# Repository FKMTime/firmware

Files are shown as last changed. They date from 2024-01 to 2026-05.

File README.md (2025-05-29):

# FKM Timer

## Main Pinout

| # | IO# | ADC/STRAP/USB | USAGE | Notes |
|-----|---|---|---|---|
| 0 | IO4 | ADC | SPI SCK | |
| 1 | IO5 | ADC | SPI MISO | |
| 2 | IO6 | | SPI MOSI | |
| 3 | IO7 | | | |
| 4 | IO8 | STRAP | | |
| 5 | IO9 | STRAP / IPU | | INTERNAL PULLUP (10kOhm) |
| 6 | IO10  | | SHIFTER DATA | |
| 7 | RXD/IO20| | JACK INPUT | |
| 8 | TXD/IO21| | SHIFTER CLK | |
| 9 | IO18  | USB | USB D- | |
| 10  | IO19  | USB | USB D+ | |
| 11  | IO3 | ADC | BUTTON INPUT | |
| 12  | IO2 | ADC / STRAP | BATTERY INPUT  | |
| 13  | IO1 | ADC | SHIFTER LATCH  | |
| 14  | IO0 | ADC | | |

**Notes:**
* **STRAP:** Strapping pin
* **IPU:** Internal Pull-up (10kOhm).
* **USB:** Pins used for USB communication.

## Shifters Configuration

| SHIFTER # | USAGE | BIT1 | BIT2 | BIT3 | BIT4 | BIT5 | BIT6 | BIT7 | BIT8 |
|---|---|---|---|---|---|---|---|---|---|
| 0 | BUTTONS MATRIX | BTN1 | BTN2 | BTN3 | BTN4 | | | | |
| 1 | LCD 16x2 | SPI_CS  | BL | RS | E | D7 | D6 | D5 | D4 |
| 2 | DISPLAY DIGIT1 | TODO | TODO | TODO | TODO | TODO | TODO | TODO | TODO |
| 3 | DISPLAY DIGIT2 | TODO | TODO | TODO | TODO | TODO | TODO | TODO | TODO |
| 4 | DISPLAY DIGIT3 | TODO | TODO | TODO | TODO | TODO | TODO | TODO | TODO |
| 5 | DISPLAY DIGIT4 | TODO | TODO | TODO | TODO | TODO | TODO | TODO | TODO |
| 6 | DISPLAY DIGIT5 | TODO | TODO | TODO | TODO | TODO | TODO | TODO | TODO |
| 7 | DISPLAY DIGIT6 | TODO | TODO | TODO | TODO | TODO | TODO | TODO | TODO |

## PCB
Pcb files are available as easyeda pro project.
File `FKM3.epro`

## 3D design 
You can view it and/or export it on onshape: 
 - [v1](https://cad.onshape.com/documents/a197fb44982d02cf4b905a34/w/d4d582c400841c8d2afd5356/e/063a9ed468737fb6f67b27f0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)
 - [v2](https://cad.onshape.com/documents/b9e6ecc4d8625f5993c3f9f8/w/500dd0485ca5c8c194e3d3fd/e/a40639e650796ab94408e0d7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)

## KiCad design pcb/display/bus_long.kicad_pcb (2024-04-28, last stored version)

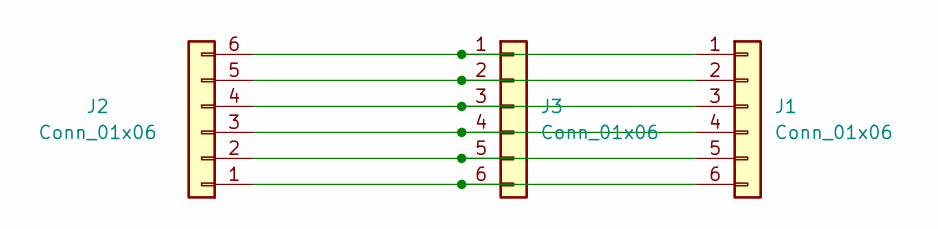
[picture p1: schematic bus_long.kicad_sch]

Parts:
J1, J2, J3: Conn_01x06; PinHeader_1x06_P2.54mm_Vertical

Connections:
unnamed: J1.1, J2.6, J3.1
unnamed: J1.2, J2.5, J3.2
unnamed: J1.3, J2.4, J3.3
unnamed: J1.4, J2.3, J3.4
unnamed: J1.5, J2.2, J3.5
unnamed: J1.6, J2.1, J3.6

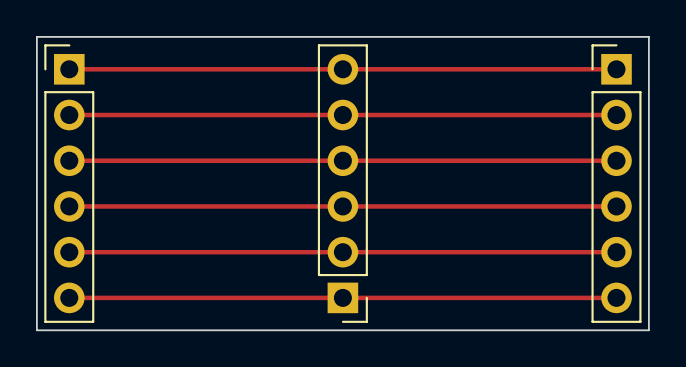
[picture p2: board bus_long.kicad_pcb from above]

Board: 2 copper layers, 34.0 x 16.3 mm, 3 parts (0 on the bottom side), 6 nets.

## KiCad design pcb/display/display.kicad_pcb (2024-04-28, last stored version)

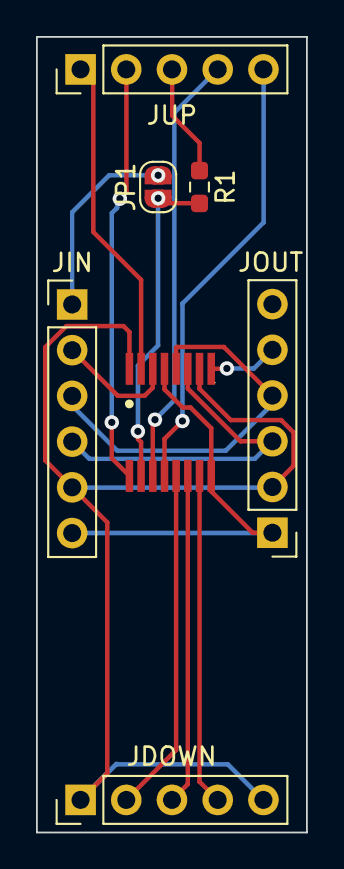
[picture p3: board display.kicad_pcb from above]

Board: 2 copper layers, 15.0 x 44.2 mm, 7 parts (0 on the bottom side), 16 nets.

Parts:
JDOWN: DOWN; PinHeader_1x05_P2.54mm_Vertical
JIN: INPUT; PinHeader_1x06_P2.54mm_Vertical
JOUT: OUTPUT; PinHeader_1x06_P2.54mm_Vertical
JP1: SolderJumper_2_Open; SolderJumper-2_P1.3mm_Open_RoundedPad1.0x1.5mm
JUP: UP; PinHeader_1x05_P2.54mm_Vertical
R1: R220; R_0603_1608Metric_Pad0.98x0.95mm_HandSolder
U1: 74HC595; TSSOP16

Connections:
8_O: JIN.1, JP1.2 (B)
+5V: JDOWN.1, JDOWN.5, JIN.5, JOUT.2, U1.10 (~SRCLR), U1.16 (VCC)
DS: JIN.2, U1.14 (SER)
DS_O: JOUT.5, U1.9 (QH')
GND: JIN.6, JOUT.1, U1.8 (GND), U1.13 (~OE)
unnamed: JUP.3, R1.1
QA: JUP.1, U1.15 (QA)
QB: JUP.2, U1.1 (QB)
QC: JP1.1 (A), R1.2, U1.2 (QC)
QD: JUP.4, U1.3 (QD)
QE: JUP.5, U1.4 (QE)
QF: JDOWN.2, U1.5 (QF)
QG: JDOWN.3, U1.6 (QG)
QH: JDOWN.4, U1.7 (QH)
SHCP: JIN.4, JOUT.3, U1.11 (SRCLK)
STCP: JIN.3, JOUT.4, U1.12 (RCLK)

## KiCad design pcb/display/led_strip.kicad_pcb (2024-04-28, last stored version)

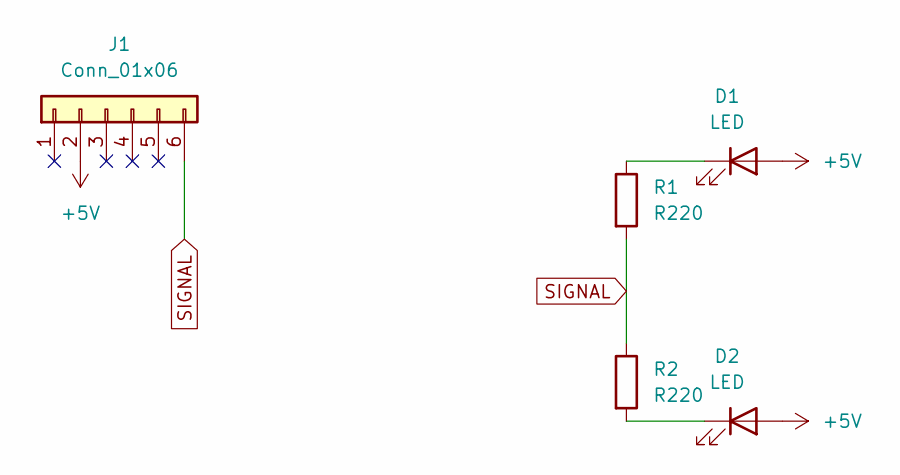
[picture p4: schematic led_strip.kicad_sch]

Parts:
D1, D2: LED; LED_D3.0mm
J1: Conn_01x06; PinHeader_1x06_P2.54mm_Vertical
R1, R2: R220; R_0603_1608Metric_Pad0.98x0.95mm_HandSolder

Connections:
+5V: D1.2 (A), D2.2 (A), J1.2
unnamed: D1.1 (K), R1.1
unnamed: D2.1 (K), R2.2
SIGNAL: J1.6, R1.2, R2.1

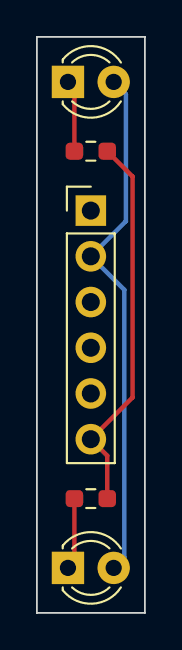
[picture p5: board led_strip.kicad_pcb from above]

Board: 2 copper layers, 6.0 x 32.0 mm, 5 parts (0 on the bottom side), 4 nets.

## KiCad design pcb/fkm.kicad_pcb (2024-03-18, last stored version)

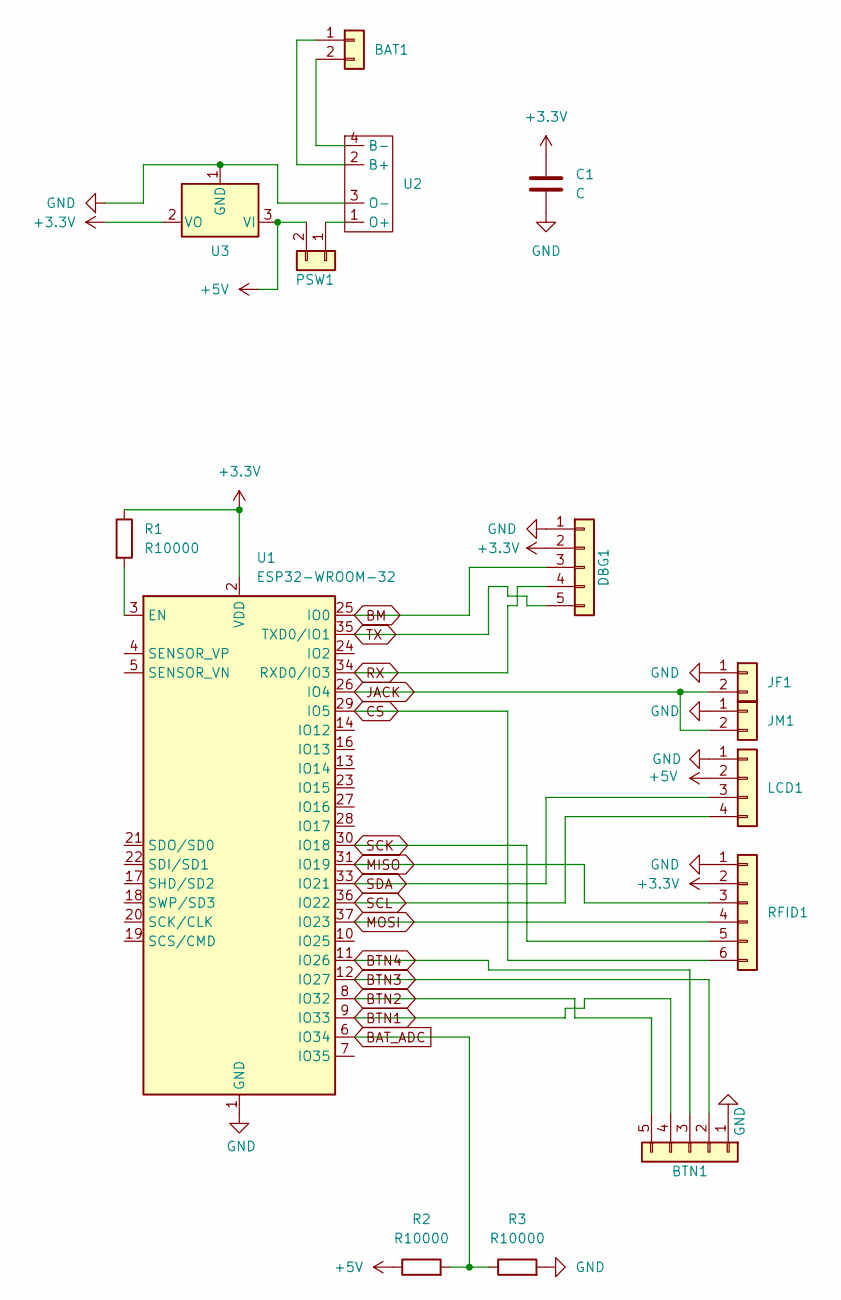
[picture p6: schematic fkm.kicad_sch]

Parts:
BAT1: BAT1; PinHeader_1x02_P2.54mm_Vertical
BTN1: Conn_01x05; PinHeader_1x05_P2.54mm_Vertical
C1: C; C_0805_2012Metric_Pad1.18x1.45mm_HandSolder
DBG1: Conn_01x05; PinHeader_1x05_P2.00mm_Vertical
JF1: JACK_FEMALE; PinHeader_1x02_P2.54mm_Vertical
JM1: JACK_MALE; PinHeader_1x02_P2.54mm_Vertical
LCD1: LCD; PinHeader_1x04_P2.54mm_Vertical
PSW1: POWER_SW; PinHeader_1x02_P2.54mm_Vertical
R1, R2, R3: R10000; R_0805_2012Metric_Pad1.20x1.40mm_HandSolder
RFID1: RFID; PinHeader_1x06_P2.54mm_Vertical
U1: ESP32-WROOM-32
U2: 18650; 18650usbc
U3: AMS1117-3.3; SOT-223-3_TabPin2

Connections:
+3.3V: C1.2, DBG1.2, R1.1, RFID1.2, U1.2 (VDD), U3.2 (VO)
+5V: LCD1.2, PSW1.2, R2.1, U3.3 (VI)
BAT_ADC: R2.2, R3.1, U1.6 (IO34)
BM: DBG1.3, U1.25 (IO0)
BTN1: BTN1.4, U1.9 (IO33)
BTN2: BTN1.5, U1.8 (IO32)
BTN3: BTN1.2, U1.12 (IO27)
CS: RFID1.6, U1.29 (IO5)
GND: BTN1.1, C1.1, DBG1.1, JF1.1, JM1.1, LCD1.1, R3.2, RFID1.1, U1.1 (GND), U1.15 (GND), U1.38 (GND), U1.39 (GND), U2.3 (O-), U3.1 (GND)
JACK: JF1.2, JM1.2, U1.26 (IO4)
MISO: RFID1.3, U1.31 (IO19)
MOSI: RFID1.4, U1.37 (IO23)
unnamed: BAT1.1, U2.2 (B+)
unnamed: BAT1.2, U2.4 (B-)
unnamed: BTN1.3, U1.11 (IO26)
unnamed: PSW1.1, U2.1 (O+)
unnamed: R1.2, U1.3 (EN)
RX: DBG1.4, U1.34 (RXD0/IO3)
SCK: RFID1.5, U1.30 (IO18)
SCL: LCD1.4, U1.36 (IO22)
SDA: LCD1.3, U1.33 (IO21)
TX: DBG1.5, U1.35 (TXD0/IO1)

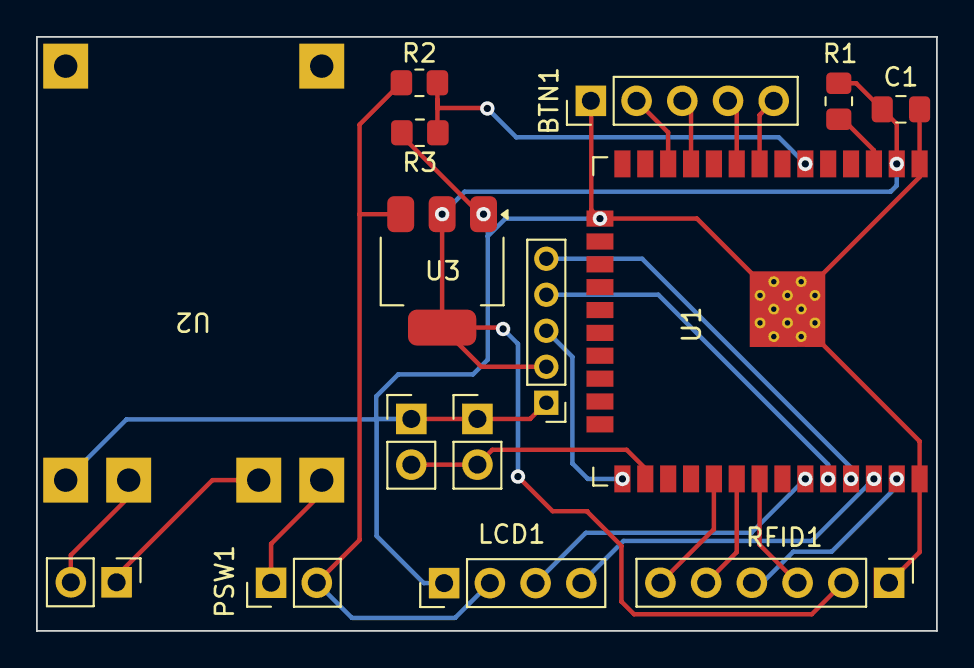
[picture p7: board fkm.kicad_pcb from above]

Board: 2 copper layers, 50.0 x 33.0 mm, 15 parts (0 on the bottom side), 22 nets.

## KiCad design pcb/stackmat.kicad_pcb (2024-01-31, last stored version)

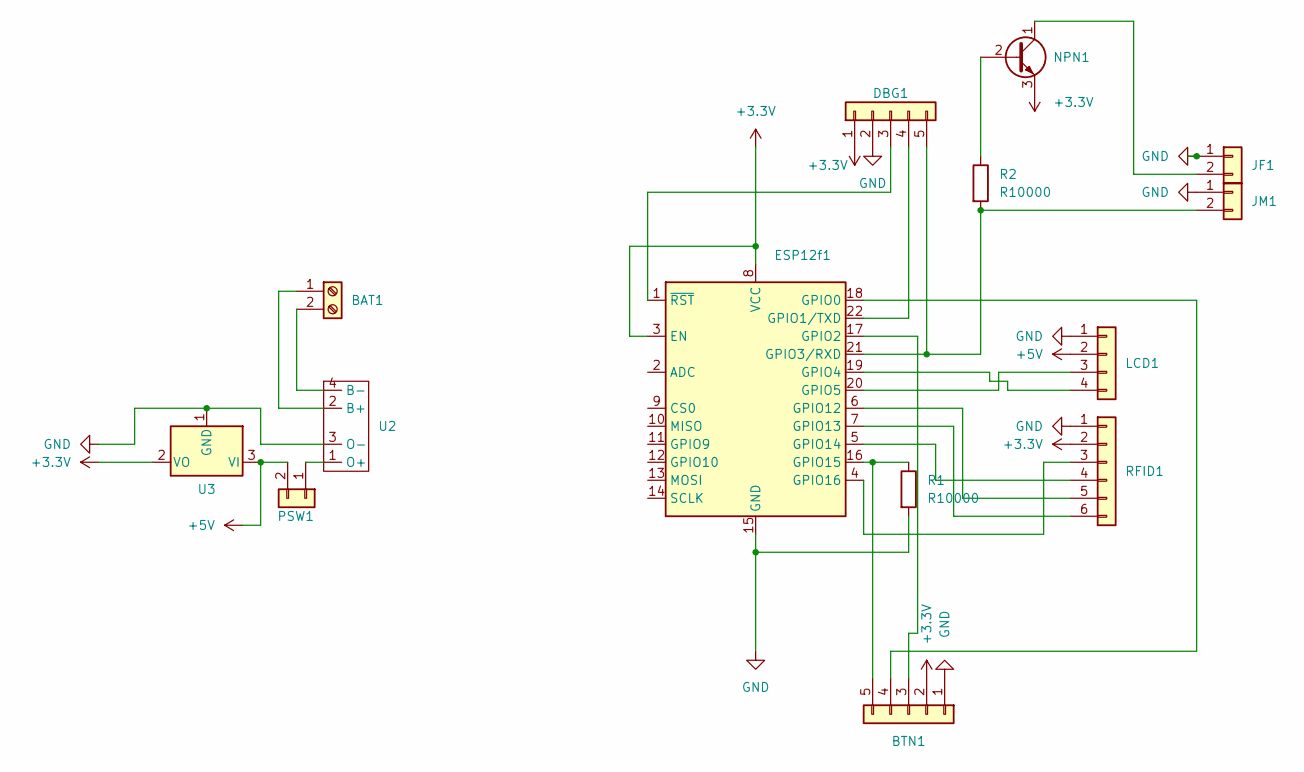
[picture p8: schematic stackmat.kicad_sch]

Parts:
BAT1: Screw_Terminal_01x02; TerminalBlock_4Ucon_1x02_P3.50mm_Horizontal
BTN1: Conn_01x05; PinHeader_1x05_P2.54mm_Vertical
DBG1: Conn_01x05; PinHeader_1x05_P2.54mm_Vertical
ESP12f1: ESP-12F/E; ESP-12E
JF1: JACK_FEMALE; PinHeader_1x02_P2.54mm_Vertical
JM1: JACK_MALE; PinHeader_1x02_P2.54mm_Vertical
LCD1: LCD; PinHeader_1x04_P2.54mm_Vertical
NPN1: BC337; TO-92_Inline
PSW1: POWER_SW; PinHeader_1x02_P2.54mm_Vertical
R1, R2: R10000; R_Axial_DIN0204_L3.6mm_D1.6mm_P7.62mm_Horizontal
RFID1: RFID; PinHeader_1x06_P2.54mm_Vertical
U2: 18650; 18650usbc
U3: AMS1117-3.3; SOT-223-3_TabPin2

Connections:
+3.3V: BTN1.2, DBG1.1, ESP12f1.3 (EN), ESP12f1.8 (VCC), NPN1.3 (E), RFID1.2, U3.2 (VO)
+5V: LCD1.2, PSW1.2, U3.3 (VI)
GND: BTN1.1, DBG1.2, ESP12f1.15 (GND), JF1.1, JM1.1, LCD1.1, R1.2, RFID1.1, U2.3 (O-), U3.1 (GND)
unnamed: BAT1.1, U2.2 (B+)
unnamed: BAT1.2, U2.4 (B-)
unnamed: BTN1.3, ESP12f1.17 (GPIO2)
unnamed: BTN1.4, ESP12f1.18 (GPIO0)
unnamed: BTN1.5, ESP12f1.16 (GPIO15), R1.1
unnamed: DBG1.3, ESP12f1.1 (~RST)
unnamed: DBG1.4, ESP12f1.22 (GPIO1/TXD)
unnamed: DBG1.5, ESP12f1.21 (GPIO3/RXD), JM1.2, R2.2
unnamed: ESP12f1.19 (GPIO4), LCD1.4
unnamed: ESP12f1.20 (GPIO5), LCD1.3
unnamed: ESP12f1.6 (GPIO12), RFID1.5
unnamed: ESP12f1.7 (GPIO13), RFID1.6
unnamed: ESP12f1.5 (GPIO14), RFID1.4
unnamed: ESP12f1.4 (GPIO16), RFID1.3
unnamed: JF1.2, NPN1.1 (C)
unnamed: NPN1.2 (B), R2.1
unnamed: PSW1.1, U2.1 (O+)

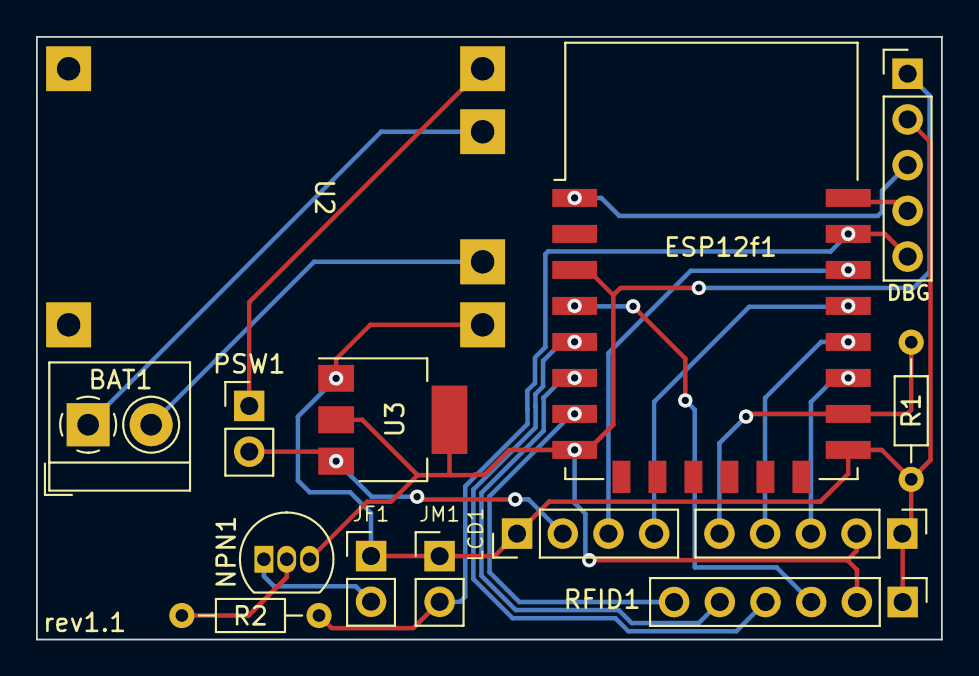
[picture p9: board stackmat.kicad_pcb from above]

Board: 2 copper layers, 50.3 x 33.5 mm, 14 parts (0 on the bottom side), 20 nets.

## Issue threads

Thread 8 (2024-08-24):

More verbose device logs

filipton, 2024-08-24:
More logging in firmware. Micro-connector shouldn't print these logs into stdout - but it should store them in files (device-id)-(date).log

Closed 2024-08-28.

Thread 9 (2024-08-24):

New pcb design (v3)

filipton, 2024-08-24:
Pcb with a size of fkm top cover, with buttons, rfid, jack's soldered directly onto PCB - so less cables.

Remaning cables:
- LCD (4PIN connector)
- ON/OFF Switch (2PIN connector)

Layout idea:

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

filipton, 2024-12-30:
# To Fix

- [ ] Ground usb-c shell
- [ ] missing on/off switch pads (split VBUS)
- [ ] **Connect VBUS to shifters (instead of +5V)**
- [ ] Maybe add capacitors on VBUS?
- [ ] Re-think PSU (2 schottky diodes on input doesnt work, p-mosfet (disabled by usb voltage) doesnt work) - maybe just use some PMIC with charging?
- [ ] Maybe limit current/voltage on usb-c input (screen contrast is shit on usb if its good on battery and vice versa)

filipton, 2024-12-31:
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

Load sharing circuit

filipton, 2025-01-01:
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
Reverse polarity protection

Closed 2025-02-22.

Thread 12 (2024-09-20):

New rust based firmware

filipton, 2024-09-20:
Firwmare for esp32c3. [Pinout sheet](https://docs.google.com/spreadsheets/d/11cCbbXgz5qSA6mDK2ferCEzVc-j3fR25RjB6trtU-28/edit?usp=sharing).

### TODO:

- [x] Project setup (on new branch)
- [x] WIFI (with wifi manager)
- [x] MDNS search for micro-connector
- [x] Websocket connection to micro-connector
- [x] Ota updates via ws
- [x] Stackmat UART RX
- [x] Battery % measurement
- [x] Buttons handler
- [x] RFID scanner
- [x] Drive LCD Display
- [x] LCD with scenes (like in previous firmware) - maybe scene will be enum with displayed data as values to it?
- [x] FKM logic (all things as 2.X)
- [x] Drive 8segment big display
- [ ] Versioning
- [ ] Auto sleep (on new firmware - wait for new esp-hal and esp-wifi)
- [ ] Macros based translation system
   - From json file generate 2d array (first dimension - language, second dimension - translation)
   - Generate function to return index in array based on langauge and on translation_key (for example "en", "startup" -> (0, 0) )
   - Or better idea, convert all translations into single big string, and return from function offset in that string (would be faster and easier to encode in eeprom)

Closed 2024-11-17.

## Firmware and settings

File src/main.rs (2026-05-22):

#![no_std]
#![no_main]
#![feature(impl_trait_in_assoc_type)]
#![deny(clippy::unwrap_used, clippy::expect_used, clippy::panic)]

extern crate alloc;
use crate::consts::NVS_SIGN_KEY;
use alloc::rc::Rc;
use alloc::string::ToString;
use board::Board;
use consts::LOG_SEND_INTERVAL_MS;
use embassy_executor::Spawner;
use embassy_sync::signal::Signal;
use embassy_time::{Instant, Timer};
use esp_backtrace as _;
use esp_hal::interrupt::software::SoftwareInterruptControl;
use esp_hal_wifimanager::{Nvs, WIFI_NVS_KEY};
use esp_storage::FlashStorage;
use state::{GlobalState, GlobalStateInner, SavedGlobalState, Scene, ota_state, sleep_state};
use structs::ConnSettings;
use utils::{logger::FkmLogger, set_brownout_detection, spawn_task};
use ws_framer::{WsUrl, WsUrlOwned};

mod bluetooth;
mod board;
mod buttons;
mod consts;
mod mdns;
mod rfid;
mod stackmat;
mod state;
mod structs;
mod translations;
mod utils;
mod version;
mod ws;

#[cfg(feature = "v3")]
mod battery_v3;
#[cfg(feature = "v3")]
mod lcd_v3;

#[cfg(feature = "v4")]
mod battery_v4;
#[cfg(feature = "v4")]
mod lcd_v4;

#[cfg(feature = "qa")]
mod qa;

pub fn custom_rng(buf: &mut [u8]) -> Result<(), getrandom::Error> {
    for chunk in buf.chunks_mut(4) {
        let random_u32 = unsafe { &*esp_hal::peripherals::RNG::PTR }
            .data()
            .read()
            .bits();

        let len = chunk.len();
        chunk[..].copy_from_slice(&random_u32.to_be_bytes()[..len]);
    }

    Ok(())
}
getrandom::register_custom_getrandom!(custom_rng);
esp_bootloader_esp_idf::esp_app_desc!();

#[esp_rtos::main]
async fn main(spawner: Spawner) {
    let peripherals = esp_hal::init({
        let mut config = esp_hal::Config::default();
        config = config.with_cpu_clock(esp_hal::clock::CpuClock::_80MHz);

        config
    });

    esp_alloc::heap_allocator!(size: 120 * 1024);
    /*
    {
        const HEAP_SIZE: usize = 8 * 1024;

        #[unsafe(link_section = ".dram2_uninit")]
        static mut HEAP2: core::mem::MaybeUninit<[u8; HEAP_SIZE]> =
            core::mem::MaybeUninit::uninit();

        #[allow(static_mut_refs)]
        unsafe {
            esp_alloc::HEAP.add_region(esp_alloc::HeapRegion::new(
                HEAP2.as_mut_ptr() as *mut u8,
                core::mem::size_of_val(&*core::ptr::addr_of!(HEAP2)),
                esp_alloc::MemoryCapability::Internal.into(),
            ));
        }
    }
    */

    set_brownout_detection(false);
    let board = Board::init(peripherals);
    let software_interrupt = SoftwareInterruptControl::new(board.sw_interrupt);
    esp_rtos::start(board.timg1.timer0, software_interrupt.software_interrupt0);
    FkmLogger::set_logger();

    log::info!("Version: {}", version::VERSION);
    log::info!("Hardware Rev: {}", version::HW_VER);
    log::info!("Firmware: {}", version::FIRMWARE);

    #[cfg(feature = "e2e")]
    log::info!("This firmware is in E2E mode!");

    #[cfg(feature = "qa")]
    log::info!("This firmware is in QA mode!");

    #[cfg(feature = "release_build")]
    crate::utils::backtrace_store::verify_panic_flag();

    let Ok(nvs) = Nvs::new_from_part_table(unsafe { board.flash.clone_unchecked() }) else {
        utils::error_log::add_error(utils::error_log::codes::WRONG_PARTITION_TABLE).await;
        #[cfg(feature = "v3")]
        lcd_v3::lcd_show_critical_code(board.lcd, utils::error_log::codes::WRONG_PARTITION_TABLE)
            .await;

        #[cfg(feature = "v4")]
        lcd_v4::lcd_show_critical_code(
            board.i2c,
            board.display_rst,
            utils::error_log::codes::WRONG_PARTITION_TABLE,
        )
        .await;

        loop {
            log::error!("Wrong partition table! Re-flash firmware with espflash!");
            Timer::after_millis(1000).await;
        }
    };

    let reason = esp_hal::rtc_cntl::reset_reason(esp_hal::system::Cpu::ProCpu);
    let wake_reason = esp_hal::rtc_cntl::wakeup_cause();
    log::info!("Wake reason: {:?} {:?}", reason, wake_reason);

    utils::error_log::load_error_log(&nvs).await;

    let global_state = Rc::new(GlobalStateInner::new(&nvs, board.aes));
    let wifi_setup_sig = Rc::new(Signal::new());
    let wifi_conn_sig = Rc::new(Signal::new());

    if let Ok(sign_key) = nvs.get::<u32>(NVS_SIGN_KEY).await {
        unsafe { crate::state::SIGN_KEY = sign_key };
    }
    #[cfg(feature = "v4")]
    if let Ok(saved_volume) = nvs.get::<u8>(crate::consts::NVS_BUZZER_VOLUME).await {
        if (crate::consts::BUZZER_VOLUME_MIN..=crate::consts::BUZZER_VOLUME_MAX)
            .contains(&saved_volume)
        {
            crate::state::set_buzzer_volume(saved_volume);
        } else {
            log::warn!(
                "Ignoring invalid saved buzzer volume: {} (valid range {}..={})",
                saved_volume,
                crate::consts::BUZZER_VOLUME_MIN,
                crate::consts::BUZZER_VOLUME_MAX
            );
        }
    }

    #[cfg(feature = "v3")]
    spawn_task(
        &spawner,
        "lcd_v3::lcd_task",
        lcd_v3::lcd_task(board.lcd, global_state.clone(), wifi_setup_sig.clone()),
    );
    #[cfg(feature = "v4")]
    spawn_task(
        &spawner,
        "lcd_v4::lcd_task",
        lcd_v4::lcd_task(
            board.i2c.clone(),
            board.display_rst,
            global_state.clone(),
            wifi_setup_sig.clone(),
        ),
    );

    #[cfg(feature = "v3")]
    spawn_task(
        &spawner,
        "battery_v3::battery_read_task",
        battery_v3::battery_read_task(board.battery, board.adc1, global_state.clone()),
    );
    #[cfg(feature = "v4")]
    spawn_task(
        &spawner,
        "battery_v4::battery_read_task",
        battery_v4::battery_read_task(board.i2c.clone(), global_state.clone()),
    );

    spawn_task(
        &spawner,
        "buttons::buttons_task",
        buttons::buttons_task(
            global_state.clone(),
            #[cfg(feature = "v4")]
            board.buttons,
            #[cfg(feature = "v3")]
            board.button_input,
            #[cfg(feature = "v3")]
            board.buttons_shifter,
        ),
    );
    spawn_task(
        &spawner,
        "stackmat::stackmat_task",
        stackmat::stackmat_task(
            #[cfg(not(feature = "timer-func"))]
            board.uart1,
            #[cfg(not(feature = "timer-func"))]
            board.stackmat_rx,
            global_state.clone(),
            #[cfg(feature = "timer-func")]
            board.pads,
        ),
    );
    spawn_task(
        &spawner,
        "rfid::rfid_task",
        rfid::rfid_task(
            #[cfg(feature = "v4")]
            board.i2c.clone(),
            #[cfg(feature = "v4")]
            board.buzzer,
            #[cfg(feature = "v3")]
            board.miso,
            #[cfg(feature = "v3")]
            board.mosi,
            #[cfg(feature = "v3")]
            board.sck,
            #[cfg(feature = "v3")]
            board.cs,
            #[cfg(feature = "v3")]
            board.spi2,
            #[cfg(feature = "v3")]
            board.spi_dma,
            global_state.clone(),
        ),
    );

    #[cfg(feature = "qa")]
    spawn_task(
        &spawner,
        "qa::qa_processor",
        qa::qa_processor(global_state.clone()),
    );

    let mut wm_settings = esp_hal_wifimanager::WmSettings {
        wifi_panel: esp_hal_wifimanager::include_minified!("src/panel.html"),
        wifi_conn_signal: Some(wifi_conn_sig.clone()),
        ..Default::default()
    };

    wm_settings.ssid.clear();
    _ = core::fmt::write(
        &mut wm_settings.ssid,
        format_args!("FKM-{:X}", crate::utils::get_efuse_u32()),
    );

    // mark ota as valid
    {
        if let Ok(mut ota) =
            esp_hal_ota::Ota::new(FlashStorage::new(unsafe { board.flash.clone_unchecked() }))
        {
            let res = ota.ota_mark_app_valid();
            if let Err(e) = res {
                log::error!("Ota mark app valid failed: {e:?}");
                utils::error_log::add_error(utils::error_log::codes::OTA_MARK_VALID_FAILED).await;
            }
        }
    }

    Timer::after_millis(500).await;
    let wifi_res = esp_hal_wifimanager::init_wm(
        wm_settings,
        &spawner,
        #[cfg(feature = "qa")]
        None,
        #[cfg(not(feature = "qa"))]
        Some(&nvs),
        board.wifi,
        unsafe { board.bt.clone_unchecked() },
        Some(wifi_setup_sig),
    )
    .await;

    let Ok(mut wifi_res) = wifi_res else {
        log::error!("WifiManager failed!!! Restarting in 1s!");
        utils::error_log::add_error(utils::error_log::codes::WIFI_MANAGER_FAILED).await;
        utils::error_log::save_error_log(&nvs).await;
        Timer::after_millis(1000).await;
        esp_hal::system::software_reset();
    };

    {
        global_state.state.lock().await.wifi_connected = Some(true);
    }

    #[cfg(feature = "qa")]
    crate::qa::send_qa_resp(crate::qa::QaSignal::WifiSetup);

    let conn_settings: ConnSettings = wifi_res
        .data
        .take()
        .and_then(|d| serde_json::from_value(d).ok())
        .unwrap_or_default();

    let mut parse_retry_count = 0;
    let ws_url = loop {
        let url = if conn_settings.mdns || conn_settings.ws_url.is_none() || parse_retry_count > 0 {
            log::info!("Starting mdns lookup...");
            global_state.state.lock().await.scene = Scene::MdnsWait;
            let mdns_res = mdns::mdns_query(wifi_res.sta_stack).await;
            log::info!("Mdns result: {mdns_res:?}");

            mdns_res.to_string()
        } else {
            conn_settings.ws_url.clone().unwrap_or_default()
        };

        let ws_url = WsUrl::from_str(&url);
        match ws_url {
            Some(ws_url) => break WsUrlOwned::new(&ws_url),
            None => {
                parse_retry_count += 1;
                log::error!("Mdns parse failed! Retry ({parse_retry_count})..");
                Timer::after_millis(1000).await;
                if parse_retry_count > 3 {
                    log::error!("Cannot parse wsurl! Reseting wifi configuration!");
                    utils::error_log::add_error(utils::error_log::codes::MDNS_WS_URL_PARSE_FAILED)
                        .await;
                    utils::error_log::save_error_log(&nvs).await;
                    _ = nvs.delete(WIFI_NVS_KEY).await;
                    Timer::after_millis(1000).await;

                    esp_hal::system::software_reset();
                }

                continue;
            }
        }
    };

    utils::backtrace_store::read_saved_backtrace().await;

    let ws_sleep_sig = Rc::new(Signal::new());
    spawn_task(
        &spawner,
        "ws::ws_task",
        ws::ws_task(
            wifi_res.sta_stack,
            ws_url,
            global_state.clone(),
            ws_sleep_sig.clone(),
            wifi_conn_sig,
        ),
    );
    spawn_task(&spawner, "logger_task", logger_task(global_state.clone()));

    let ble_sleep_sig = Rc::new(Signal::new());
    spawn_task(
        &spawner,
        "bluetooth::bluetooth_timer_task",
        bluetooth::bluetooth_timer_task(board.bt, global_state.clone(), ble_sleep_sig.clone()),
    );

    set_brownout_detection(true);
    global_state.state.lock().await.scene = Scene::WaitingForCompetitor;
    if let Some(saved_state) = SavedGlobalState::from_nvs(&nvs).await {
        global_state
            .state
            .lock()
            .await
            .parse_saved_state(saved_state);
    }

    let mut last_sleep = false;
    'outer: loop {
        Timer::after_millis(100).await;
        if utils::error_log::is_save_ready() {
            utils::error_log::save_error_log(&nvs).await;
            utils::error_log::clear_save_ready();
        }

        if sleep_state() != last_sleep {
            last_sleep = sleep_state();
            ble_sleep_sig.signal(last_sleep);
            if last_sleep {
                log::warn!("Entering sleep mode!");
                ws::send_frame(ws_framer::WsFrameOwned::Close(
                    4000,
                    "Going into sleep mode".to_string(),
                ))
                .await;

                // only wait that 15s when going into sleep mode (to make sure close is sent and to
                // debounce sleeps)
                let start = Instant::now();
                while start.elapsed().as_millis() < 15000 {
                    if sleep_state() != last_sleep {
                        // send sleep to ws to make sure clean state of
                        // ws is reached in next outer loop iteration
                        ws_sleep_sig.signal(true);

                        continue 'outer;
                    }

                    Timer::after_millis(100).await;
                }
            }

            ws_sleep_sig.signal(last_sleep);
            match last_sleep {
                true => wifi_res.stop_radio(),
                false => wifi_res.restart_radio(),
            }
        }
    }
}

#[embassy_executor::task]
async fn logger_task(global_state: GlobalState) {
    #[cfg(not(feature = "release_build"))]
    let mut heap_start = Instant::now();

    loop {
        Timer::after_millis(LOG_SEND_INTERVAL_MS).await;

        if ota_state() || sleep_state() {
            continue;
        }

        #[allow(static_mut_refs)]
        let logs_vec = unsafe {
            crate::utils::logger::LOGS_WRITER.get_vec(Some(crate::stackmat::CURRENT_TIME))
        };

        if !logs_vec.is_empty() {
            ws::send_frame(ws_framer::WsFrameOwned::Binary(logs_vec)).await;
        }

        #[cfg(not(feature = "release_build"))]
        if (Instant::now() - heap_start).as_millis() >= consts::PRINT_HEAP_INTERVAL_MS {
            if global_state.state.lock().await.server_connected == Some(true) {
                log::info!("{}", esp_alloc::HEAP.stats());
            }

            heap_start = Instant::now();
        }
    }
}

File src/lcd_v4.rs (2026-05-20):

use crate::{
    consts::{
        DEEPER_SLEEP_AFTER_MS, INSPECTION_TIME_PLUS2, LCD_INSPECTION_FRAME_TIME, SLEEP_AFTER_MS,
    },
    state::{
        ErrorLogEntryStage, GlobalState, MenuScene, Scene, SignaledGlobalStateInner,
        deeper_sleep_state, sleep_state,
    },
    translations::{TranslationKey, get_translation, get_translation_params},
    utils::{
        lcd_resourcese::{CrossedIcon, Resources},
        shared_i2c::SharedI2C,
        stackmat::ms_to_time_str,
    },
};
use alloc::{
    format,
    rc::Rc,
    string::{String, ToString},
    vec::Vec,
};
use anyhow::{Result, anyhow};
use display_interface_i2c::I2CInterface;
use embassy_sync::{blocking_mutex::raw::NoopRawMutex, signal::Signal};
use embassy_time::{Delay, Instant, Timer};
use embedded_graphics::{
    Drawable,
    mono_font::MonoTextStyle,
    pixelcolor::BinaryColor,
    prelude::*,
    primitives::{Line, PrimitiveStyle, Rectangle},
    text::{Alignment, Baseline, Text, TextStyle, TextStyleBuilder},
};
use embedded_graphics_framebuf::FrameBuf;
use embedded_layout::{
    layout::linear::{FixedMargin, Horizontal, LinearLayout},
    prelude::*,
    view_group::ViewGroup,
};
use embedded_text::{
    TextBox,
    alignment::{HorizontalAlignment, VerticalAlignment},
    style::TextBoxStyleBuilder,
};
use esp_hal::gpio::Output;
use oled_async::{displays::ssd1309::Ssd1309_128_64, mode::GraphicsMode};

pub const FBUF_WIDTH: usize = 128;
pub const FBUF_HEIGHT: usize = 64;
pub const FBUF_SIZE: usize = FBUF_WIDTH * FBUF_HEIGHT;

pub struct OledData<'a> {
    pub fbuf: FrameBuf<BinaryColor, &'a mut [BinaryColor; FBUF_SIZE]>,
    pub disp: GraphicsMode<Ssd1309_128_64, I2CInterface<SharedI2C>>,
}

impl OledData<'_> {
    pub async fn flush(&mut self) -> Result<()> {
        self.disp
            .draw_iter(&self.fbuf)
            .map_err(|e| anyhow!("{e:?}"))?;
        self.disp.flush().await.map_err(|e| anyhow!("{e:?}"))?;

        Ok(())
    }

    pub fn clear_main(&mut self) -> Result<()> {
        self.fbuf.fill_solid(&MAIN_RECT, BinaryColor::Off);
        Ok(())
    }
}

pub const MAIN_RECT: Rectangle = Rectangle::new(Point::new(0, 11), Size::new(128, 53));
pub const TOPBAR_RECT: Rectangle = Rectangle::new(Point::new(0, 0), Size::new(128, 10));
pub const DETAILS_VISIBLE_LINES: usize = 5;
pub const NORMAL_FONT: MonoTextStyle<'_, BinaryColor> = MonoTextStyle::new(
    &embedded_graphics::mono_font::ascii::FONT_7X13,
    BinaryColor::On,
);
pub const SMALL_FONT: MonoTextStyle<'_, BinaryColor> = MonoTextStyle::new(
    &embedded_graphics::mono_font::ascii::FONT_6X9,
    BinaryColor::On,
);
pub const TIMER_FONT: MonoTextStyle<'_, BinaryColor> =
    MonoTextStyle::new(&profont::PROFONT_14_POINT, BinaryColor::On);
pub const SMALL_TIMER_FONT: MonoTextStyle<'_, BinaryColor> =
    MonoTextStyle::new(&profont::PROFONT_7_POINT, BinaryColor::On);

pub const TEXT_CENTER: TextStyle = TextStyleBuilder::new()
    .alignment(Alignment::Center)
    .baseline(Baseline::Middle)
    .build();
pub const TEXT_TOPBAR: TextStyle = TextStyleBuilder::new()
    .alignment(Alignment::Right)
    .baseline(Baseline::Top)
    .build();

fn center_screen<VG: ViewGroup>(
    content: VG,
) -> LinearLayout<Horizontal<embedded_layout::align::vertical::Center>, VG> {
    LinearLayout::horizontal(content)
        .with_alignment(embedded_layout::align::vertical::Center)
        .arrange()
        .align_to(
            &Rectangle::new(Point::new(0, 0), Size::new(128, 64)),
            embedded_layout::align::horizontal::Center,
            embedded_layout::align::vertical::Center,
        )
}

fn center_layout<VG: ViewGroup>(
    content: VG,
) -> LinearLayout<Horizontal<embedded_layout::align::vertical::Center>, VG> {
    LinearLayout::horizontal(content)
        .with_alignment(embedded_layout::align::vertical::Center)
        .arrange()
        .align_to(
            &MAIN_RECT,
            embedded_layout::align::horizontal::Center,
            embedded_layout::align::vertical::Center,
        )
}

fn center_text_layout(text: &str) -> TextBox<'_, MonoTextStyle<'_, BinaryColor>> {
    let textbox_style = TextBoxStyleBuilder::new()
        .alignment(HorizontalAlignment::Center)
        .vertical_alignment(VerticalAlignment::Middle)
        .build();

    TextBox::with_textbox_style(text, MAIN_RECT, NORMAL_FONT, textbox_style)
}

fn draw_scrollable_menu<D>(target: &mut D, items: &[&str], selected: usize)
where
    D: DrawTarget<Color = BinaryColor>,
{
    const LINE_HEIGHT: i32 = 10;
    const VISIBLE: usize = 5;
    const PADDING_X: i32 = 4;

    let menu_font = MonoTextStyle::new(
        &embedded_graphics::mono_font::ascii::FONT_6X9,
        BinaryColor::On,
    );
    let menu_font_inv = MonoTextStyle::new(
        &embedded_graphics::mono_font::ascii::FONT_6X9,
        BinaryColor::Off,
    );

    let total = items.len();
    let scroll_start = if selected + 1 >= VISIBLE {
        (selected + 1 - VISIBLE).min(total.saturating_sub(VISIBLE))
    } else {
        0
    };

    let start_y = MAIN_RECT.top_left.y;

    for (row, item) in items[scroll_start..].iter().take(VISIBLE).enumerate() {
        let item_idx = scroll_start + row;
        let y = start_y + row as i32 * LINE_HEIGHT;
        let text_y = y + LINE_HEIGHT / 2;

        if item_idx == selected {
            let bar = Rectangle::new(Point::new(0, y), Size::new(128, LINE_HEIGHT as u32));
            bar.into_styled(PrimitiveStyle::with_fill(BinaryColor::On))
                .draw(target)
                .ok();
            Text::with_text_style(
                item,
                Point::new(PADDING_X, text_y),
                menu_font_inv,
                TextStyleBuilder::new()
                    .alignment(Alignment::Left)
                    .baseline(Baseline::Middle)
                    .build(),
            )
            .draw(target)
            .ok();
        } else {
            Text::with_text_style(
                item,
                Point::new(PADDING_X, text_y),
                menu_font,
                TextStyleBuilder::new()
                    .alignment(Alignment::Left)
                    .baseline(Baseline::Middle)
                    .build(),
            )
            .draw(target)
            .ok();
        }

        if scroll_start > 0 && row == 0 {
            Text::with_text_style("^", Point::new(122, text_y), menu_font, TEXT_CENTER)
                .draw(target)
                .ok();
        }
        if scroll_start + VISIBLE < total && row == VISIBLE - 1 {
            Text::with_text_style("v", Point::new(122, text_y), menu_font, TEXT_CENTER)
                .draw(target)
                .ok();
        }
    }
}
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

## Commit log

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2023-11-12 fix: spi weirdness feat: ntp
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2024-01-11 feat: ignore timer when one time was already complete
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2024-01-23 fix: clear solver card id on timer session start
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2024-01-26 feat: custom software serial with "hw" resend (interrupts)
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2024-01-26 feat: kicad proj
    [stackmat.kicad_pcb, stackmat.kicad_sch, stackmat_panel.kicad_pcb]
2024-01-27 chore: kikit panelizer
    [stackmat.kicad_pcb, stackmat.kicad_sch, stackmat_panel.kicad_pcb]
2024-01-27 chore: kicad 7.0
    [stackmat.kicad_pcb, stackmat.kicad_sch]
2024-01-27 feat: submit time button (with pcb changes)
    [stackmat.kicad_pcb, stackmat.kicad_sch]
2024-01-27 feat(pcb): smaller size (for 2x3 pannels)
    [stackmat.kicad_pcb, stackmat.kicad_sch]
2024-01-27 feat: disable time offset changes when after submit
    [stackmat.kicad_pcb]
2024-01-27 wip(pcb): transistors instead of serial "copy"
    [stackmat.kicad_pcb, stackmat.kicad_sch]
2024-01-28 feat(pcb): one transistor design
    [stackmat.kicad_pcb, stackmat.kicad_sch]
2024-01-28 feat: hardware based serial amplifier, better submit button
    [stackmat.kicad_pcb, stackmat.kicad_sch]
2024-01-28 feat: delegate button
    [stackmat.kicad_pcb, stackmat.kicad_sch]
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2024-01-29 chore: mousebites for panel (2x1 because jlcpcb was mad)
    [stackmat.kicad_pcb]
2024-01-29 chore: smaller board (smallest i could do without changing layout) - so panelized is 102x102mm (2USD on jlcpcb)
    [stackmat.kicad_pcb]
2024-01-30 fix: lcd 5v instead of 3.3v
    [stackmat.kicad_pcb, stackmat.kicad_sch]
2024-01-30 feat: better pcb debug pins
    [stackmat.kicad_pcb, stackmat.kicad_sch]
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2024-01-31 feat: lcd printf helper (with aligments etc)
    [stackmat.kicad_pcb]
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2024-02-02 fix: sleep mode issues on buttons
2024-02-11 feat: connector to API from ws server (with simple api tester)
2024-02-13 chore: moved pcb lables for better visibility
    [stackmat.kicad_sch]
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2024-02-24 feat: timer state reset button (15s penalty button hold)
2024-02-25 fix: lcd refreshing while timer was running (when waiting for judge)
2024-02-25 fix: buttons and rfid read were disabled when timer was running (event after time finished)
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2024-02-26 chore: better dockerfile, changed pcb folder name
    [stackmat.kicad_pcb, stackmat.kicad_sch]
2024-02-26 feat(pcb): jack's without aplifiers (rev 1.2) chore(pcb): use kicad 8.0
    [fkm.kicad_pcb, fkm.kicad_sch, stackmat.kicad_pcb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]
2024-02-29 feat: refresh lcd on timer state reset (holding on submit 5s)
2024-02-29 feat: debug "snapshot" button combo chore: changed naming: solver -> competitor
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2024-03-06 chore: remove pinouts for esp32 [skip ci]
2024-03-08 fix: timer reset (on penalty button) [skip ci]
2024-03-10 wip(pcb): rev 2.0 pcb (esp32) - to re-do
    [fkm.kicad_pcb, fkm.kicad_sch]
2024-03-11 feat(pcb): battery level input (ADC)
    [fkm.kicad_pcb, fkm.kicad_sch]
2024-03-11 wip(pcb): re-wire everything (now its not messy)
    [fkm.kicad_pcb, fkm.kicad_sch]
2024-03-12 wip: utils methods for battery% calculation [skip ci]
2024-03-12 chore: remove unwraps wip: investigate errors of buttons (clearing competitor on long submit press)
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2024-03-14 feat(pcb): decoupling capacitor
    [fkm.kicad_pcb, fkm.kicad_sch]
2024-03-14 chore(pcb): better capacitor text placement
    [fkm.kicad_pcb]
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2024-03-16 fix: better battery read
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2024-03-16 feat: ota feat: send battery stats to backend
2024-03-17 fix: rfid on esp32
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2024-03-17 feat: soft power down mfrc522 module on sleep
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2024-03-18 feat(pcb): 4xbuttons output
    [fkm.kicad_pcb, fkm.kicad_sch]
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2024-04-01 chore: less trace logs (for better visibility) fix: send Going into light sleep message to ws
2024-04-03 fix: button press crash
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2024-04-08 fix: add device STATION firmware type
2024-04-14 chore: extend sleep time (to 10mins) chore: remove second reset timer state button
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2024-04-24 fix: cross device move (updates) fix: read ws url from properties instead of hostname
2024-04-26 wip: do not show device not added if device is added and no event is selected
2024-04-26 feat: method to simulate button presss (a_buttons lib)
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2024-04-27 feat(e2e): detect error timeout
    [main.rs]
2024-04-28 feat: display pcb (one digit)
    [display.kicad_pcb, display.kicad_sch]
2024-04-28 chore: better silkscreen naming on display pcb
    [display.kicad_pcb]
2024-04-28 feat(pcb): bus bars and led holder
    [bus_long.kicad_pcb, bus_long.kicad_sch, bus_short.kicad_pcb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]
2024-05-01 wip: fix docker build
    [main.rs]
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2024-05-09 feat: show different message if someone solves before card scan fix: timer(stackmat) reset logic
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2024-05-22 feat: clear display on reset timer stats
2024-05-23 chore: clear display on inspection end (2nd button click)
2024-05-23 fix: lock lcd on clear fix: do not update lastTimerState to ST_Unknown chore: add stackmat state change debug print
2024-08-24 chore: pcb decoupling capacitor value
    [fkm.kicad_sch]
2024-08-28 feat: more verbose device logs (button presses, ws messages, etc.) (closes #8)
2024-08-30 feat: do not check device_settings secondaryText and useInspection null status
2024-09-27 feat: async (embassy) + esp-hal-wifimanager (ap not working for now)
    [main.rs]
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2024-10-26 feat: first working buttons prototype (easy add handler functions)
2024-10-26 chore: print button handler errors
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2024-10-27 wip: battery percentage, lcd write spaces till end
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2024-11-01 wip: test lcd signal (print wifi/mdns wait state)
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2024-11-03 fix: reelease build crash (dma_buffers for rfid were too big) chore: cargo fmt
    [main.rs, rfid.rs, stackmat.rs]
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2024-11-06 wip: send channels for ws (TODO: rework them?)
    [rfid.rs]
2024-11-06 fix: ws framer parsing multiple frames in one tcp packet
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2024-11-09 wip: buttons state modify test feat: own arc implementation
2024-11-09 wip: own packet parse trait (for better error handling)
    [rfid.rs]
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2024-11-11 feat: show error text, and secondary_text
    [main.rs, rfid.rs, stackmat.rs]
2024-11-11 feat: inspection end button fix: competitor display after error
    [rfid.rs]
2024-11-11 feat: buttons skip other handlers
    [rfid.rs]
2024-11-11 feat: reset solve button
    [rfid.rs]
2024-11-11 fix: state issues (even bug in v2 firmware lmao)
    [stackmat.rs]
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2024-11-12 fix: old firmware bugs (e.g. dnf on inspect without competitor card) fix: display issues
    [rfid.rs, stackmat.rs]
2024-11-12 feat: delegate hold chore: cleaner action discard rules (if error, stackmat/server disconnected)
    [rfid.rs]
2024-11-12 fix: logic fixes and epoch base fix
    [rfid.rs]
2024-11-12 feat: solve confrimation reset state
    [rfid.rs, stackmat.rs]
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2024-11-15 wip: ota
    [partitions.csv]
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2024-11-15 fix: make lcd driver not-async (because of shift register)
2024-11-16 wip: test light sleep (wifi issues)
    [main.rs]
2024-11-16 fix: inspection scene refresh rate fix: delegate response change scene fix: faster stackmat timeout (500ms)
    [stackmat.rs]
2024-11-16 feat: make ota partitions bigger feat: show display test pattern on startup
    [partitions.csv]
2024-11-16 wip: new and better button handler (no dynamic dispatch)
2024-11-16 feat: use new button handler (no dynamic dispatch)
2024-11-17 feat: just use Rc instead of Arc for state (esp32c3 is single threaded so no diff)
2024-11-17 feat: update v2 firmware to use new micro-connector packets
2024-11-17 feat: simple sleep (lcd backlight) fix: do not update screen in scroll loop without any update
    [rfid.rs]
2024-11-18 feat: disable brownout detection until wifi connected
    [main.rs]
2024-11-19 fix: device add button (wrong skip check loction)
2024-12-30 explore: firmware for first pcb test (with slightly broken mcu and latch pin)
    [main.rs]
2025-01-02 wip: esp32 port (not everything, fucking dram issues)
    [main.rs, rfid.rs]
2025-01-04 wip: stackmat working wip: rfid smaller dma size
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2025-01-06 fix: pin for one broken mcu (that has different pin, because i've broken orginal one lmao)
    [main.rs]
2025-01-06 fix: ota do not send logs
    [main.rs, rfid.rs]
2025-01-08 fix: all warnings caused by esp32 port
    [main.rs, rfid.rs]
2025-01-11 fix: all clippy errors
    [main.rs, stackmat.rs]
2025-01-15 fix: clear inspection time after stackmat reset (Closes #15)
    [stackmat.rs]
2025-01-16 fix: esp32 generic build feat: change GLOBAL_LOGS to use Channel from embassy-sync
    [main.rs]
2025-01-16 fix: logs vector should be reversed before send
    [main.rs]
2025-01-16 feat: print last panic addresses fix: various fixes
    [main.rs, stackmat.rs]
2025-01-19 feat: bat_dev_lcd feature to read raw battery readings (for dev)
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2025-01-19 feat: better battery calculations feat: show battery on lcd
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2025-01-25 fix: connection through proxy (socket timeout?)
    [main.rs]
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2025-01-27 feat: backlight sleep on old esp32 based hw
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2025-01-27 fix: reversed sleep state
    [main.rs]
2025-01-28 feat: more error handling
    [main.rs]
2025-02-06 chore: remove old todo's chore: even more error handling lmao
    [main.rs, rfid.rs]
2025-02-06 fix: reset solve state on no user groups error
    [rfid.rs]
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2025-02-11 fix: esp32 build
2025-02-14 chore: remove translation string normalization (now done on micro-connector side)
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2025-02-18 fix: send test ack after data processing
    [rfid.rs, stackmat.rs]
2025-02-18 fix: change scene to waiting for competitor if timer finishes with same time
    [stackmat.rs]
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2025-02-22 chore: print heap and send battery info only if server is connected
2025-02-22 chore: replace old pcb project
    [bus_long.kicad_pcb, bus_long.kicad_sch, bus_short.kicad_pcb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]
2025-02-23 fix: show group select if timer starts after card is scanned
    [stackmat.rs]
2025-02-27 fix: generic esp32 buttons fix
    [main.rs]
2025-03-01 feat: fix timer stuck issue
    [stackmat.rs]
2025-03-07 fix: delegate wait timeout fix: new pcb rev lcd pins
2025-03-09 fix: backlight flicker on esp32c3
    [main.rs]
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2025-03-13 fix: esp32 build feat: mark ota valid after more operations
    [board.rs, main.rs]
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2025-04-05 fix: speed up cpu clock
    [main.rs]
2025-04-06 feat: use ag-lcd fork with async support fix: decrease button debounce time fix: ms time to str above 9 minutes 59seconds
    [main.rs, stackmat.rs]
2025-04-08 chore: print card skip warn msg
    [rfid.rs]
2025-04-08 fix: do not try to send frame if its too big
    [main.rs]
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2025-05-15 fix: uart slowdown issue (closes #21 #22)
    [stackmat.rs]
2025-05-15 fix: release build const
    [main.rs]
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2025-06-25 fix: build/clippy ci with removed `esp32c3` feature
2025-06-25 fix: actually fix ci
    [main.rs]
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2025-09-22 feat: auto add device feature fix: show proper ws_rw errors
2025-09-25 explore: check secured read from rfid card [skip ci]
    [rfid.rs]
2025-09-25 fix: invalidate SIGN_KEY on reset wifi
    [main.rs]
2025-09-28 fix: tls read select cancel
    [rfid.rs]
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2025-10-11 fix: do not print token in the info log (use debug)
    [board.rs, main.rs]
2025-10-14 fix: update wifimanager to fix "sticky" ble
    [main.rs]
2025-10-15 wip: try to connect to fkm display example [skip ci]
    [main.rs]
2025-10-16 wip: messy ble display re-bonding [skip ci]
    [stackmat.rs]
2025-10-17 wip: better menu scene management [skip ci]
    [rfid.rs]
2025-10-20 chore: more error handling (no unwraps, only expects in codepath's that cannot fail)
    [main.rs, stackmat.rs]
2025-11-01 fix: lcd hanging on start (fucking wifi is blocking - not my issue)
    [main.rs]
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2026-02-13 fix: esp32c3 deeper sleep
2026-02-13 fix: skip card processing when server isn't connected (closes #28)
    [rfid.rs]
2026-02-13 fix: sleep set server_connected to false
    [main.rs]
2026-02-13 fix: FRAME_CHANNEL deadlock
2026-02-13 fix: do not soft power down rfid module on sleep
    [rfid.rs]
2026-02-24 fix: rfid in qa mode
    [rfid.rs]
2026-03-09 wip: v4 firmware [SKIP CI]
    [board.rs, main.rs, rfid.rs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]
2026-03-09 wip: shared i2c struct with embedded_hal_async [SKIP CI]
    [board.rs, rfid.rs, shared_i2c.rs]
2026-03-09 wip: async oled driver [SKIP CI]
    [board.rs, main.rs]
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2026-03-12 fix: solve time not displayed when the same as last solve time
    [main.rs, stackmat.rs]
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2026-03-19 fix: delegate call translation
    [lcd_v4.rs, stackmat.rs]
2026-03-19 fix: sleep timer reset when battery percentage changes
    [battery_v4.rs, lcd_v4.rs]
2026-03-21 fix: v4 inspection time display on finished scene
    [lcd_v4.rs, stackmat.rs]
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2026-04-17 feat(v4): add buzzer and rotate lcd
    [board.rs, lcd_v4.rs, main.rs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]
2026-04-17 feat(v4): rfid buzzer volume controls
    [board.rs, lcd_v4.rs, main.rs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]
2026-04-19 fix: unwraps and expects
    [main.rs]
2026-04-19 fix: own sleep power consumption (stop wifi controller)
    [lcd_v4.rs]
2026-04-19 fix: center sleep text to the screen not to main rect
    [lcd_v4.rs]
2026-04-22 wip: error log [skip ci]
    [error_log.rs, main.rs]
2026-04-22 feat: add version to error log stacktrace
    [error_log.rs]
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2026-04-23 v4 error log details: scrollable view, full stacktrace, fix compile error (#30)
    * Add error log submenu state and interaction flow
    Agent-Logs-Url: https://github.com/FKMTime/firmware/sessions/c858a510-9b6d-44c7-a6f1-dffbab89ae2c
    * Implement v3/v4 error log submenu UI and flow
    Agent-Logs-Url: https://github.com/FKMTime/firmware/sessions/c858a510-9b6d-44c7-a6f1-dffbab89ae2c
    * Changes before error encountered
    Agent-Logs-Url: https://github.com/FKMTime/firmware/sessions/89d3fa84-427f-4508-8f14-dc7847c63c14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
    [error_log.rs, lcd_v4.rs, main.rs]
2026-04-27 fix(v3): error log menu
    [error_log.rs]
2026-04-27 fix: do not send empty logs, do not delete stacktrace on self recovery
    [main.rs]
2026-04-28 wip: add error logs for most common issues
    [battery_v4.rs, error_log.rs, lcd_v4.rs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]
2026-04-29 feat: show critical error screen when partition table is wrong
    [lcd_v4.rs, main.rs]
2026-05-11 feat: disable buzzer when inspection is disabled
    [rfid.rs]
2026-05-11 feat: show scan judge card error when competitor scanned for the second time
    [rfid.rs]
2026-05-12 fix: use sound enbaled device settings boolean
    [rfid.rs]
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2026-05-15 feat: dump crash log cmd
    [error_log.rs]
2026-05-15 chore: dump crash/error log from memory instead of nvs
    [error_log.rs]
2026-05-19 feat: limit solve time (closes #33) feat: interpolate time when timer conn lost (even after 10mins) (closes #32) chore: removed old v3 display connector support
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2026-05-20 fix: timer func stop
    [stackmat.rs]
2026-05-20 fix: deadlocks when battery gauge fails to read
    [battery_v4.rs, error_log.rs, lcd_v4.rs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]
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2026-07-18 fix(v3): button debounce
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2026-11-03 feat: send live state every second and on timer start/stop (#38)
    * feat: send live state every second and on timer start/stop
    * feat: send live state every second only while a solve is active
2026-11-09 feat: say the timer must be reset when inspection can't start (#46)
